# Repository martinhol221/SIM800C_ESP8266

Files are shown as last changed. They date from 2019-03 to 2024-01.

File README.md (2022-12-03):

* [Скачать актуальную версию прошивки 7.3 ](https://github.com/martinhol221/SIM800C_ESP8266/tree/master/firmware) обязательно перезалить дашборд
После перепрошивки зайти в меню прошивки через Web-интерфейс и сделать сброс настроек.

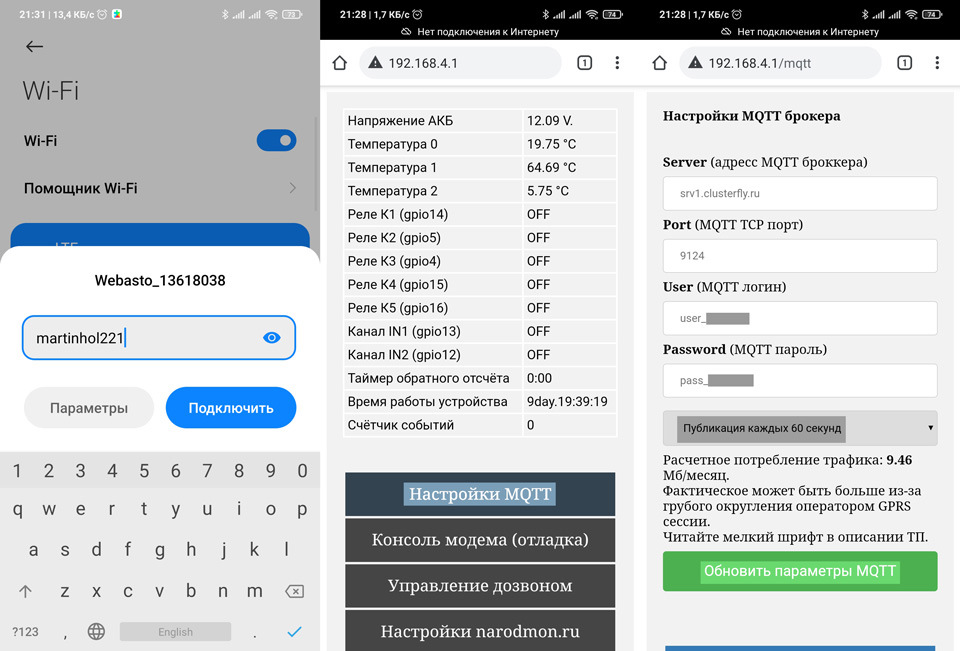
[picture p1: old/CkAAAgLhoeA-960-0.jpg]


Приложение CarMQTT Control

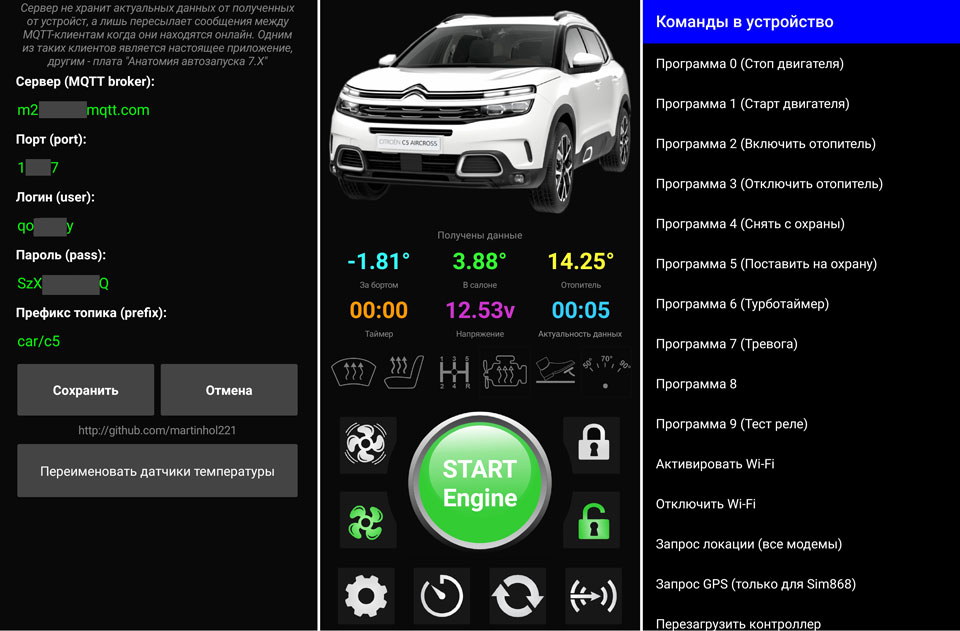
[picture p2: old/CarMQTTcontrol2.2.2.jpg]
* 

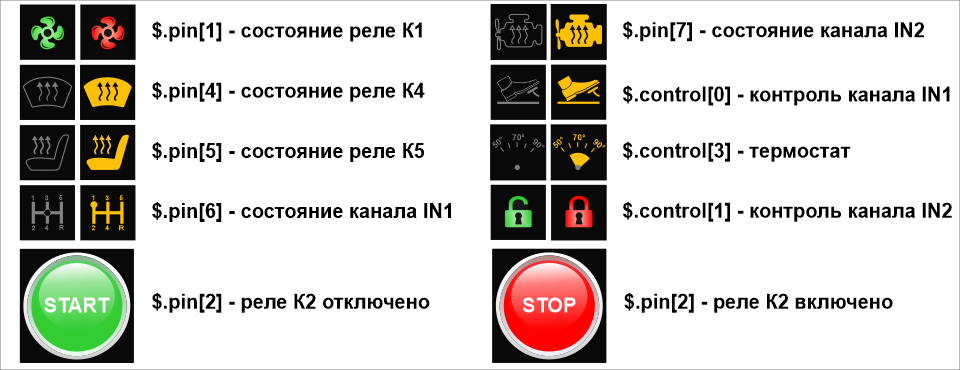
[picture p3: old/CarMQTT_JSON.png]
* 

## Коротко о протоколе MQTT в конкретной прошивке 

Приложение подписывается на топик `car/c5/pub` - и отправляет команды в топик устройства.
Устройство подписывается на топик `car/c5/sub` и реагирует на следующие сообщения в этом топике:

* `prog0`...`prog9` - исполняет одну из 10 програм храниящихся в настройках ESP8266
* `wifion`      - включает WI-FI точку доступа `Webasto_123456` с паролем `martinhol221`
* `wifioff`     - отключает WI-FI точку доступа
* `control1=1`  - активирует контроль за каналом IN1 (педаль тормоза, или другие функции)
* `control1=0`  - деактивирует контроль за каналом IN1
* `control2=1`  - активирует контроль за каналом IN2 (датчик удара, объема, или другие функции)
* `control2=0`  - деактивирует контроль за каналом IN2
* `termostat=1` - активирует контроль вилкой температур заданных в настройках (термостат, автопрогрев)
* `termostat=1` - деактивирует контроль температурой
* `termostat=0` - деактивирует контроль температурой
* `reboot` -  перезагрузка ESP8266
* `timer=15` - установка таймера обратного отсчета на 15 минут 
* `starter=1600` - установка максимального времени прокрутки стартера в 1.600 сек. 
* `ussd`  - публикует в топик `car/c5/pub/ussd` баланс	`Balans=5.00r MB=454` (только GSM кодировка)
* `debug` - публикует в топик `car/c5/pub/debug` JSON строку статистики соединения `{"debug":[1,0,0,0,5,5,1]}`
* `update`- публикует в топик `car/c5/pub`	JSON строку с данными текущего состояния 
`{"pin":[13.73,1,1,0,0,0,1,0],"temp":[14.81,14.50,14.13],"time":[45,3455,4],"control":[1,0,1,0]}`, извлечь необходимый параметр можно с помощью [JSON pach](https://github.com/json-path/JsonPath) доступного в большинстве MQTT приложений

* `$.pin[0]` - вернёт напряжение питания устройства (13.73)
* `$.pin[1]` - вернёт состояние реле `K1` (1) - включено
* `$.pin[2]` - вернёт состояние реле `K2` (1) - включено
* `$.pin[3]` - вернёт состояние реле `K3` (0) - отключено 
* `$.pin[4]` - вернёт состояние реле `K4` (0) - отключено
* `$.pin[5]` - вернёт состояние реле `K5` (0) - отключено 
* `$.pin[6]` - вернёт состояние входа `IN1` (0) - нет напряжения
* `$.pin[7]` - вернёт состояние входа `IN2` (1) - есть напряжение
* `$.temp[0]` - вернёт температуру датчика с индексом `0`  (14.81)
* `$.temp[1]` - вернёт температуру датчика с индексом `1`  (14.50)
* `$.temp[2]` - вернёт температуру датчика с индексом `2`  (14.13)
* `$.time[0]` - вернёт значение таймера обратного отсчета `45` минут 
* `$.time[1]` - вернёт время работы устройства `3455`
* `$.control[0]` -  контроль за каналом IN1 `1` активен (нейтральная передача)
* `$.control[1]` -  контроль за каналом IN2 `0` не активен (датчик удара)
* `$.control[3]` -  контроль за вилкой температур `0` не активен 

## Редактор програм

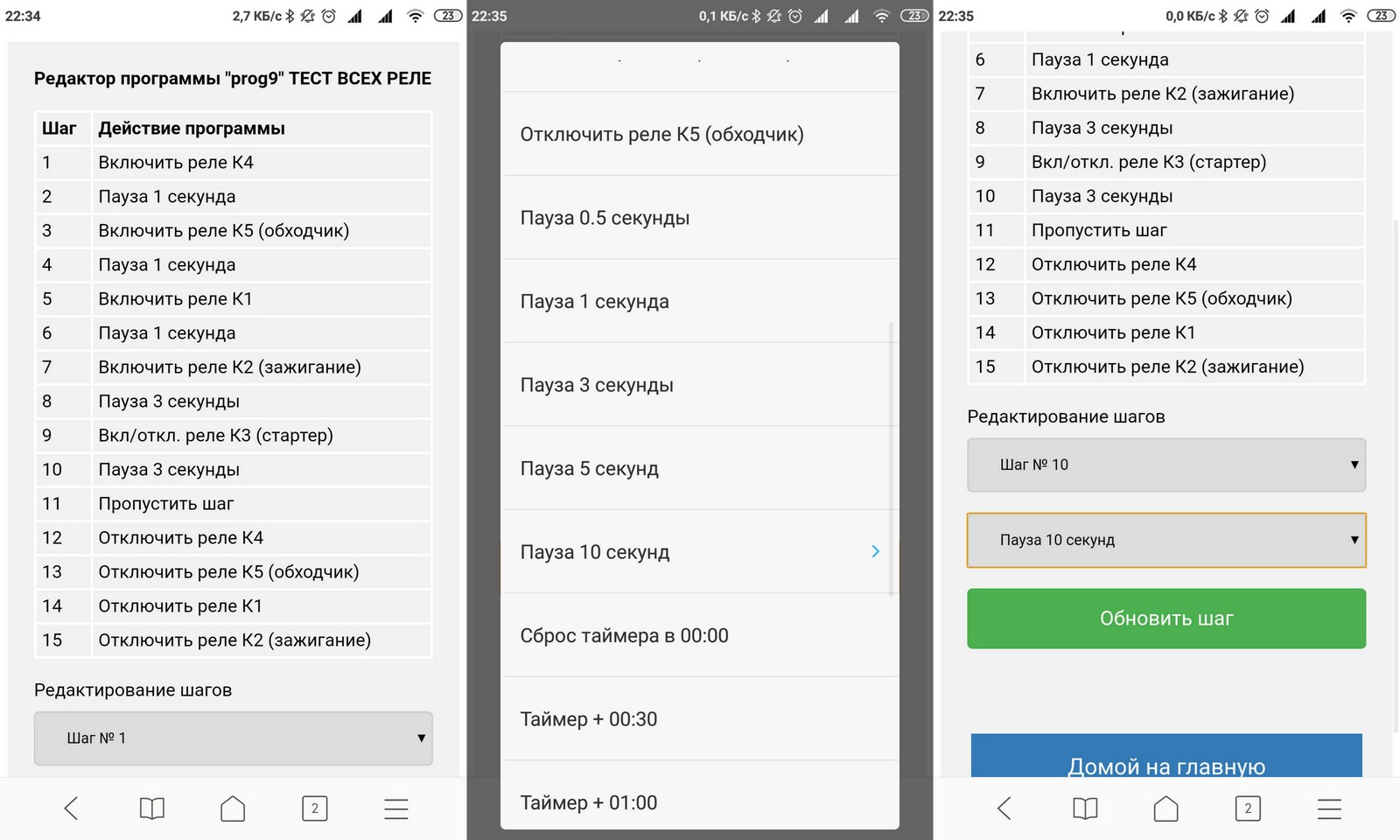
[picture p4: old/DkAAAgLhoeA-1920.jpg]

  
## Контроль включения стартера

В настройках интерфейса можно задать условие из трех пунктов для разрешение включения стартера в зависмости он напряжения АКБ  (при работающем двигателе оно будет выше 12,90V), и состояние каналов  `IN1` или `IN2`. обычно, они подключается на выход концевика педали тормоза (для АКПП), или на датчик включенной передачи (МКПП).

Длительность работы стартера задается в милисекундах (1 / 1000 сек.)

Поконтролю зарядки АКБ после запуска устройство понимает что двигатель запущен, контроль можно отключить.

## Контроль по аппаратному прерыванию каналов IN1 и IN2 и кнопке

* Cмена состояния каналов `IN1` или `IN2` с `0` на `12V` вызывает программы `prog0`... `prog9` заданные в настройках для этого канала
* Cмена состояния Кнопки с `3.3V` на `0` вызывает программы `prog0`... `prog9` или активации Wi-Fi

**********
## Управление по термостату

В настройках устройства задается:

* минимальная температура при падении ниже которой происходит вызов програм `prog0`... `prog9`
* максимальная температура при  превышении которой происходит вызов програм `prog0`... `prog9`
* индекс подключенного датчика с которого контролируется температура
* флаг активациии или деактивации режима

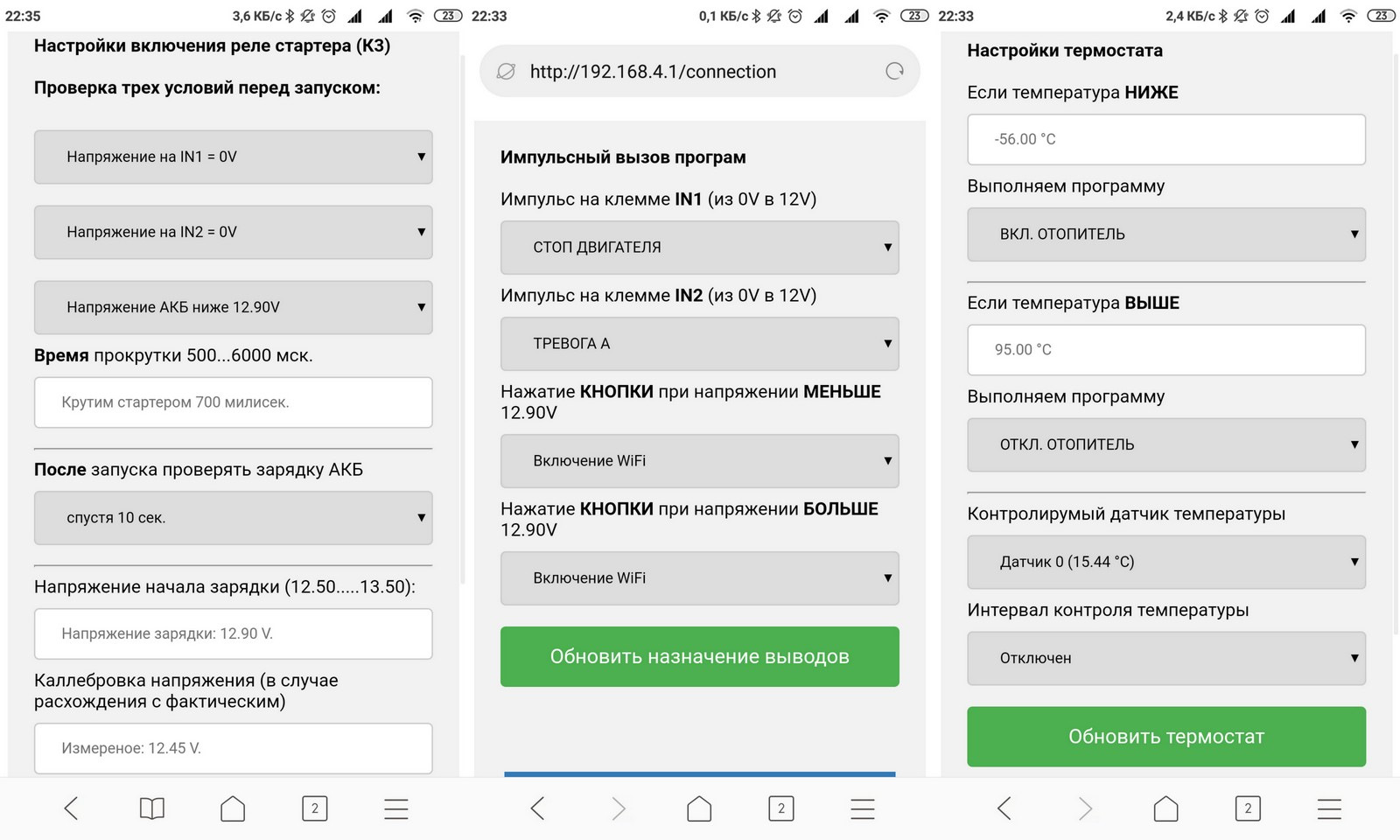
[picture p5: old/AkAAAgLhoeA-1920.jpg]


## Активация WI-FI точки доступа

Устройство генерирует точку доступа SSID `Webasto_123456` на 10 минут с паролем `martinhol221` , к которой можно подключиться с телефона для обновления прошивки или внесения изменений в настройки, страница настроек доступна по адресу `http://192.168.4.1`.
Активация WIFI возможна несколькими способами

* Запрос из приложения `wifion`
* Замыкание `SCL` на `GND` вызывает включение WiFi если это настроено в пункте контроля каналов.
* Снятие и подача питания на устройство

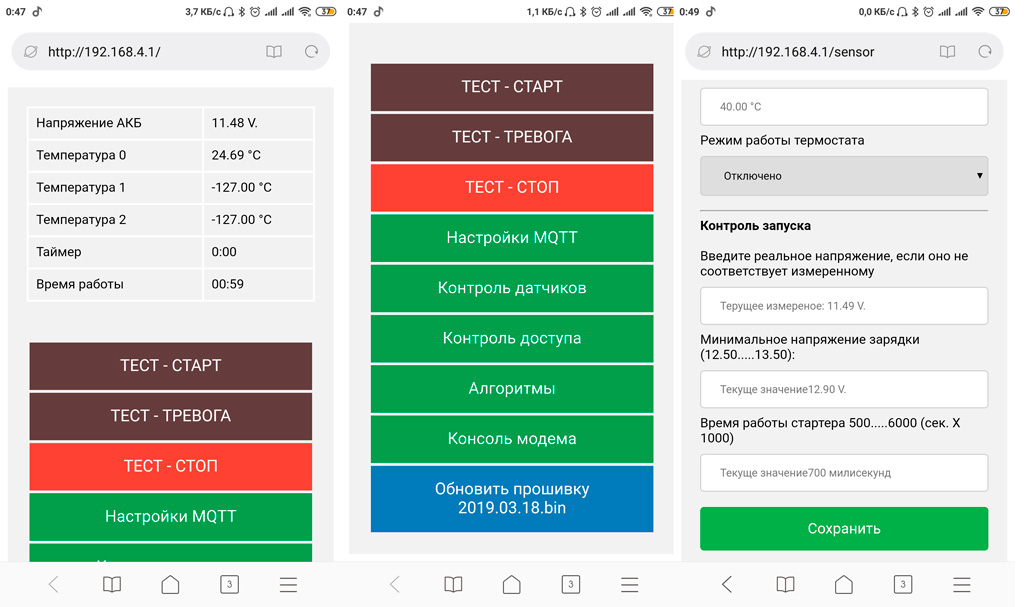
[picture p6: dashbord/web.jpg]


По прошествии 10 минут WiFi отключается и устройство уходит в энергосберегающий режим потребляя ток 17-22 мА.

## Управление по звонку с вводом DTMF команд

При звонке на устройство модем снимет вызов только с телефона хозяина, после "снятия трубки" будет ожидать ввода команд

* `#0*1234` - вызовет программу `prog0`
* `#1*1234` - вызовет программу `prog1`
* `#2*1234` - вызовет программу `prog2`
* `#3*1234` - вызовет программу `prog3`
* `#555`    - Отправит SMS через 10 сек. 
* `#777`    - Перезагрузит модем. 
* `#888`    - активирует вайфай. 
* `#999`    - Перезагрузит ESP. 

где `1234`     - пинкод для управления   

****
## управление GET-запросом
http://192.168.4.1/sensor?name1=TEMP4&val1=-12.24   // Передача на narodmon.ru значения датчика -12.24 с именем TEMP4  

http://192.168.4.1/set?PROG=0                       // Выполнить программу 0 - (СТОП)

http://192.168.4.1/set?PROG=6                       // Выполнить программу 6 

http://192.168.4.1/set?AT_CMD=ATD%2B37512345678%3B // Звоним на нужный номер +37512345678  

http://192.168.4.1/set?AT_CMD=ATH0                  // Завершаем вызов

http://192.168.4.1/sms?sms_phone=%2B3751234567&sms_text=Trevoga.Datchik1 // отправка sms 

## Выбор MQTT приложения в телефон для управления по GPRS

Для Android
* [MQTT Strt Engine (специально написанное)](https://play.google.com/store/apps/details?id=appinventor.ai_martinhol2221.CarMqttControl)
* [MQTT Dash Google Play](https://play.google.com/store/apps/details?id=net.routix.mqttdash&hl=ru) рекомендую
* [IoT MQTT Panel](https://play.google.com/store/apps/details?id=snr.lab.iotmqttpanel.prod)
* [IoT MQTT Dashboard](https://play.google.com/store/apps/details?id=com.thn.iotmqttdashboard)
* [Linear MQTT Dashboard](https://play.google.com/store/apps/details?id=com.ravendmaster.linearmqttdashboard)

Для IOS: 
[IoT OnOff](https://itunes.apple.com/be/app/iot-onoff/id1267226555?mt=8) не на всех версиях ОС, может не коннекстится с брокером

## Выбор MQTT брокера (далее сервера)

**********************************

MQTT broker

https://www.cloudmqtt.com

https://clusterfly.ru

https://wqtt.ru

http://mqtt.by

### Потребление трафика:

Один пакет GPRS данных состоит в среднем из 100 - 110 байт, отправляется устройством каждую минуту, 100 байт х 60 минут х 24 часа х 31 день = около 4.5 MB/мес, однако на практике оператор трафик считают больший, у меня набегает 9.5 Мб в месяц.
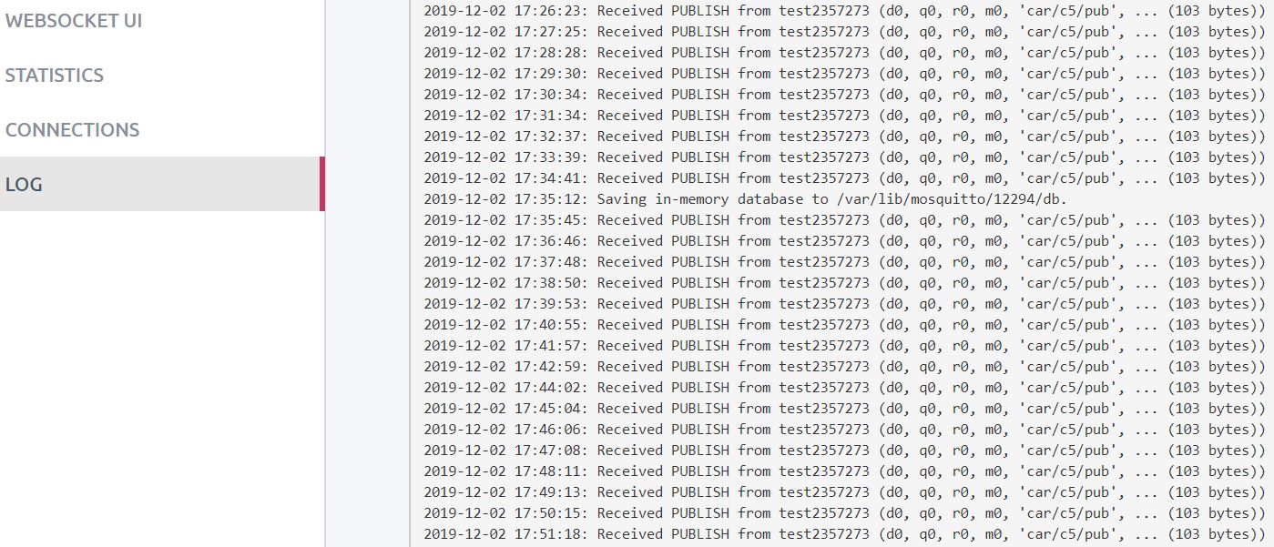
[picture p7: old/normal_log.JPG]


Стоит отметить что сотовые операторы по разному округляют трафик в конце сессии, в результате чего, списывать с баланса могут в разы больше фактически затраченного.



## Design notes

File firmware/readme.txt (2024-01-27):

SSID: Webasto_XXXXXXX (10 min.)
PASS: martinhol221

ESP-12E OR ESP-12F
ADDR: 0x00000

ESP-8266    --> SIM800C (SIM800L) 
TXD (GPIO1) --> RXD
RXD (GPIO3) --> TXD

1-Wire (DS18B20, DS2413) - GPIO0 
Button on PCB- GPIO2
IN1- GPIO13  
IN2- GPIO12 

распиновка реле:
K1-  GPIO14  
K2-  GPIO5  
K3-  GPIO4  
K4-  GPIO15  
K5-  GPIO16  

07.10.2019 - добавил опцию выгрузки / загрузки настроек через JSON строку
12.10.2019 - имена програм можно редактировать, добавил кнопку "назад в редактор", из приложенимя можно "привязывать" 
первый и второй какналы к программам prog0 ... prog9. после перепрошивки делаем сброс настроек до заводских настроек
19.10.2019 - имя и пароль wifi сети сохраняется после перезагрузки, побавил возможность внутри выполняемой программы 
включать и отключать выполнение програм по инмпульсам на каналах IN1 (prog0) и IN2 (prog7). 
29.10.2019 - контроль температуры термостатом происходит один раз в минуту, 5 ошибок `+CME ERROR: 3` подряд перезагружает
модем востанавливая связь, программы prog0....prog7 исполняются только ОДИН РАЗ подряд, вне зависимости от источника 
их вызова, если предыдущая прошивка свежее 19.10.2019 то сбрасывать настройки не нужно
31.10.2019 - пофиксил баг с пропаданием связи после 'длинных' програм запуска, 5 ошибок `CLOSED` подряд перезагрузит модем.
02.11.2019 - При звонке на симку DTMF ввод 888 активирует вайфай, ввод 777 перезагружает модем.
06.11.2019 - увеличелось время отклика, повысилась стабильность соединения, 
появилась статистика {"debug":[CONNECT OK,CONNECT_FAIL,+CME ERROR,CLOSED,пакетов отправлено, подтверждено, перезагрузок
модема]}
08.11.2019 - пофиксил баг с некоррректным определением DTMF команд перезагрузка модема `777`, вкл. WIFI `888`, перезагрузка 
всего `999` 
16.11.2019+ - отключил функцию LWT нужен тест на длительность, костыли для стабильности 5 `CLODED` (5 минут) - перезагрузка
модема, 5 - перезагрузок модема (30 минут) - перезагрузка ESP (сброс времени работы) 
30.11.2019 - изменён режим комнотроля каналов IN1 и IN2, и режим активации термостата, сейчас ставить пины на контроль можно из 
дашборда (который так же нужно обновить)
16.12.2019 - измененено условие перезагрузки модема: 7 ошибок `CLODED` ТОЛЬКО ПРИ УСЛОВИИ что модем ЗАРЕГИСТРИРОВАН в сети,
ошибка будет игнорироваться, если модем вне сети покрытия. Появился режим 'Стартер по тахометрту' - отключение стартера в 
процессе запуска, при условии, что импульсы с датчика распредвала (IN2 до 12V) будет меньше XXX милискунд, которые 
устанавливаются на странице настроек стартера, у меня нет возможность тестировать.
11.01.2020 - Добавлена поддержка виртуальных реле К6 - К13 через расширитель портов на DS2413 подключаемого к шине датчиков.
14.01.2020 - Исправил баг с отключением WIFI после перезагрузки, когда в настройках стояло `Не выключать`.
10.02.2020 - Исправил баг из-за которого контроллер " забывал " выключать включенные реле при перезагрузке. Добавил выгрузку данных на народмон, скрытая страница 192.168.4.1/narodmon
18.02.2020 - Выделена отдельная кнопка настроек народмон, востановление забытого пароля wifi: подать питание и в течении 0,5 сек зажать
кнопку на 2 сек. и отпустить, код загрузится с настройами по умолчанию. Раньше для входа в безопасный режим нужно было подавать 5-6 вольт при подаче питания, что было не удобно.
08.03.2020 - по MQTT уходит время наработки в часах, таймер обратного отсчёта в секндах, работает стабильно с mqtt.4api.ru
21.03.2020 - GET запрос http://192.168.4.1/sensor?name1=TEMP4&val1=-12.24&name2=TEMP5&val2=14.68 с показаниями датчиков будет ретранслирован в народмон
21.07.2020 - добавлен сканер устрйств на однопроводной шине данных, счётчик событий, опция в программе разрешающая ее повтор множество раз подряд.
19.09.2020 - добавлен вывод данных о состоянии всех выходов и статистика по подключению модема для приложения CarMQTTControl (вызов через " Управление - Диагностика")
17.01.2021 - сделана автоматическая генерация преффиксов топиков при обновлении настроек MQTT, данные по диагностики сейчас притетают вcar/c5/pub/diagnostics
ответ {"status":[0,0,0,0,675,675,0,3,97,692]}, для этого изменена подписа в приложении начиная с CarMqttControl_2.2.6 и выше
16.10.2021 - добавил опцию задержки (2 минуты) выключения реле К1, будет полезно при использовании циркуляционного насоса вебасто.
19.10.2021 - добавил опцию задержки (3 минуты) включения реле К4, будет полезно для активации климат-контроля
23.10.2023 - крупное обновление;
- Изменена разметка страницы, шрифты, перенесены разделы по другим категориям;
- Полностью переписан интерфейс редактора сценариев, увеличено количество шагов до 20-ти сразу для всех сценариев, исчез глюк с недогрузкой страницы. Стало возможно редактирование всех 20 шагов не покидая страницу и сохраняя их залпом все сразу;
- Изменена разметка страницы консоли модема, сейчас текст не вылазит за пределы страницы;
- При установке пин-кода 0000 в настройках вызова, при дозвоне происходит сброс вызова и запуск сценария 1;
- Содержимое страницы настроек каналов переехало на страницу настроек сценариев;
- На страницу настройки стартера добавил поле минимального напряжения для включения стартера, будет полезно при автопрогреве, если не произошёл запуск несколько раз подряд и аккум высел ниже этого порога то автопрогрев (термостат) отключается что бы не убивать далее АКБ.
- При проверке каналов IN1 и IN2 перед запуском ранее к двум логическим состояниям добавил "любое состояние", временно убрал поле для тахометра, позже верну.
- Скрыл кнопку перехода на страницу настройки народмона из-за бага с ошибкой +CME Error 3, сама настройки по пержнему доступна по адресу 192.168.4.1/narodmon;
- В новой прошивке сдвинулись реле, теперь реле K6 и К7 пока не задействованы, а все реле реализованные через расширитель портов сейчас отображентся как порт 1А, порт 1B и т.д. и работают в импульсном режиме (вкл. пауза 1 сек., выкл.)
- Полностью пересмотрена структура JSON файла для хранения настроек, от этого после перехода на новую прошивку активация не подтягивается и настройки вытавляются по умолчанию, ключ нужно прописывать заново;
Можно обновиться до новой прошивки, не активируя ее старым ключом, поизучать и снова прошиться старой прошивкой от октября 21 октября 2021 и настройки восстановятся.

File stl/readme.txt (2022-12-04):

4x18650-TK102B -  переходник для крепления 4х аккумуляторов формата 18650 платы GPS треккера TK-102B
PSA_ring_41.5 - кольцо на антенну иммобилайзера замка зажигания Пежо, Ситроен 
Renault_ring_59.5 - кольцо на антенну иммобилайзера замка зажигания Рено, Веста 
PCF7936 - каркас катушки чипа транспондера.
Mazda-6 - каркас катушки с квадратным отверстием 14х14 мм

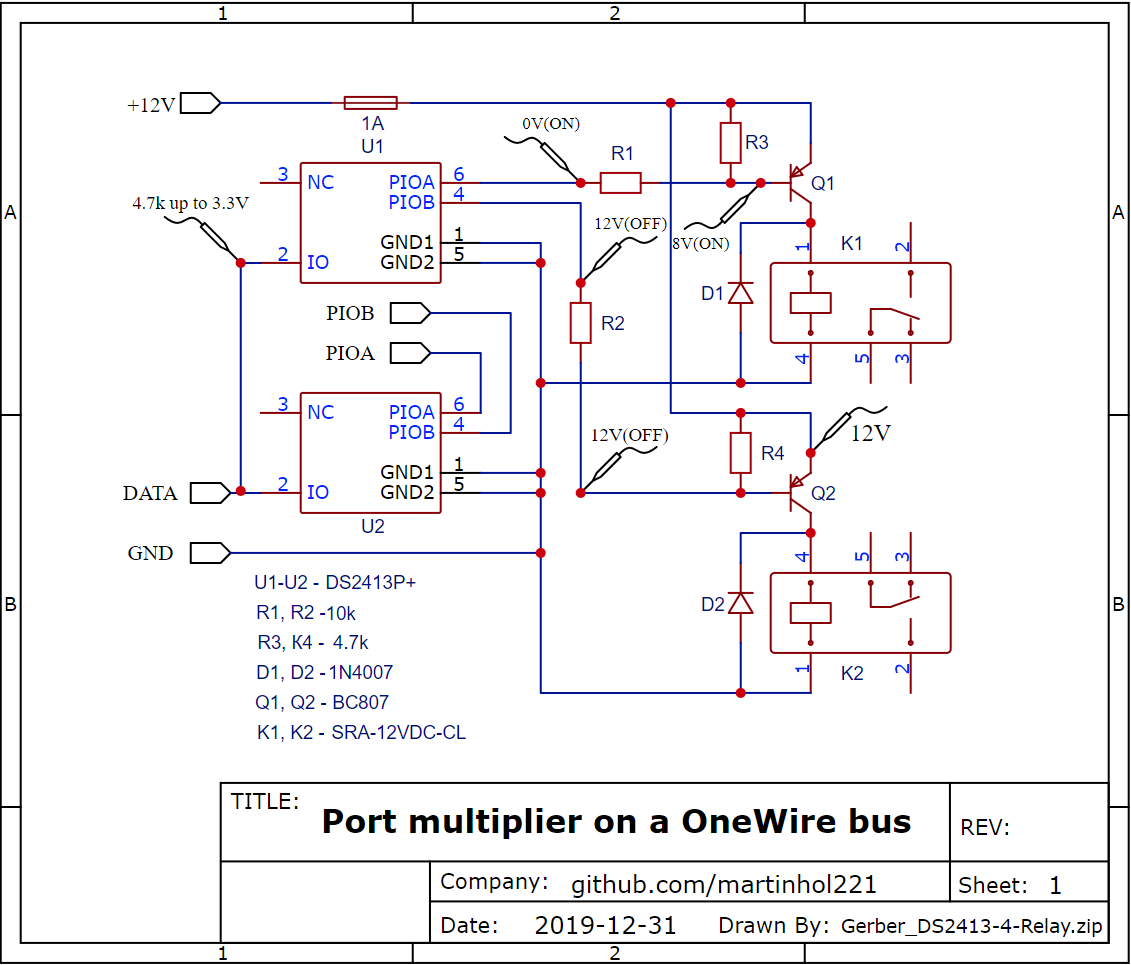
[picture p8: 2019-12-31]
PCB/DS2413-2-Relay.png

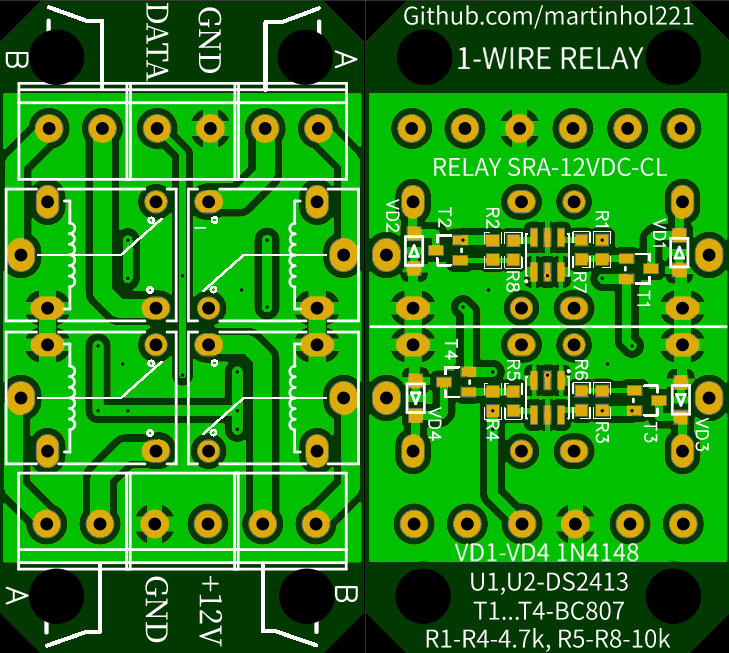
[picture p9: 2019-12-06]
PCB/Gerber_DS2413-4-Relay.jpg

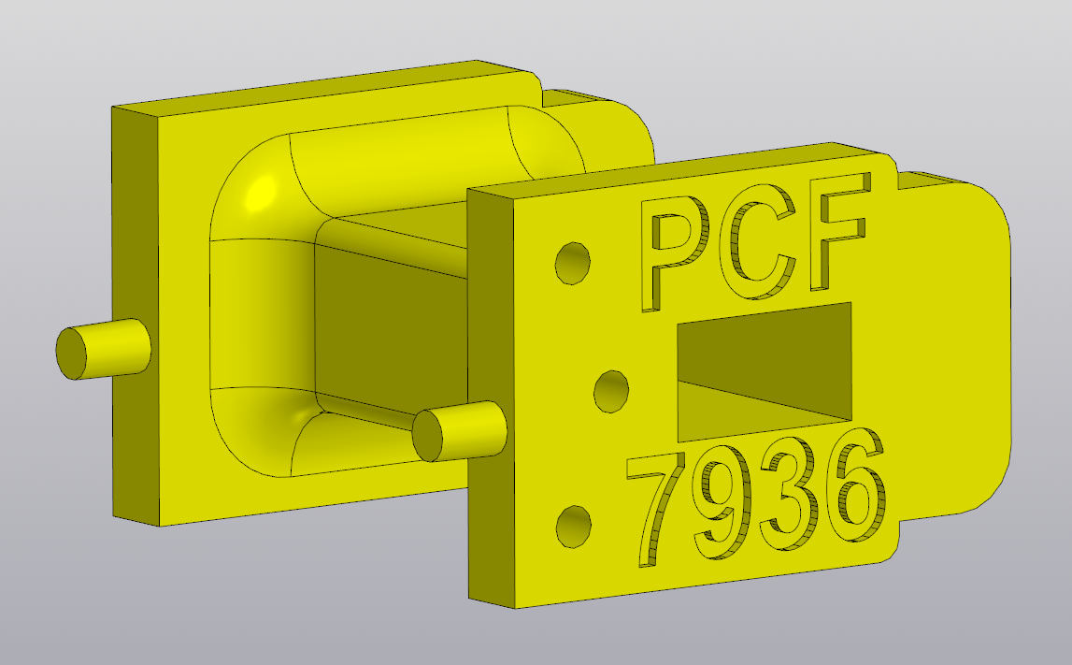
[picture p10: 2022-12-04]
stl/PCF7936.png

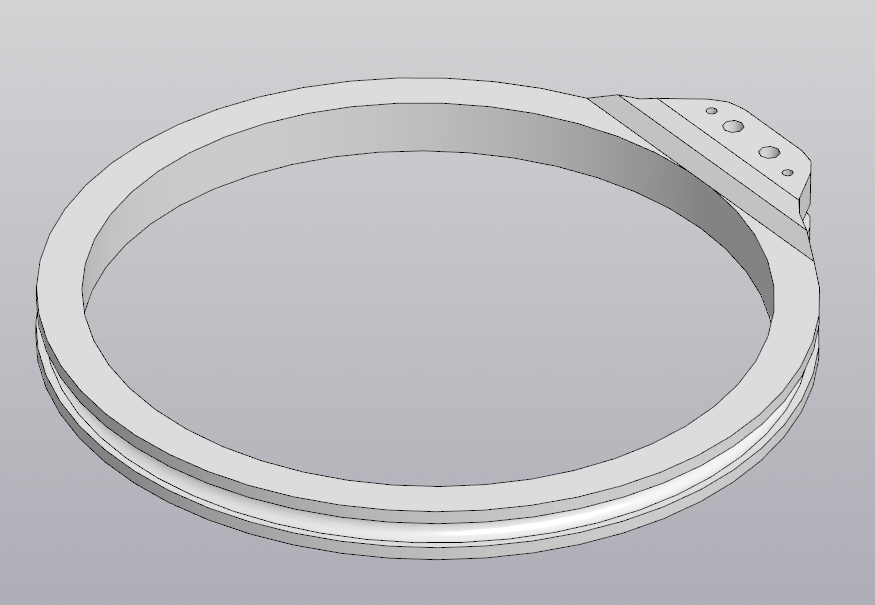
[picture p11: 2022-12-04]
stl/Renault_ring_59.5.png

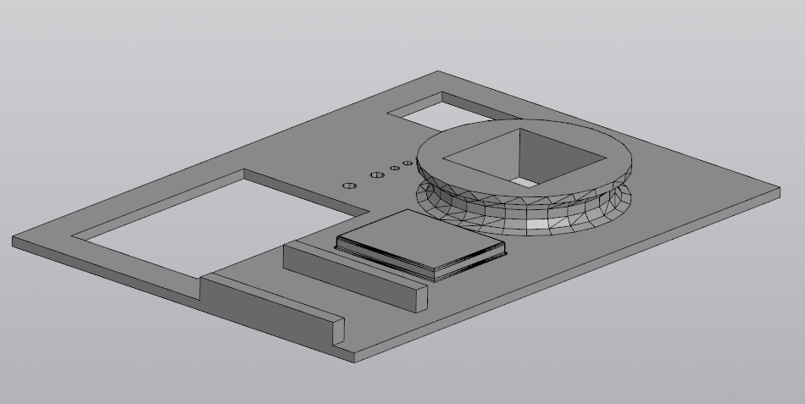
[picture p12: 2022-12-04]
stl/Mazda-6.png

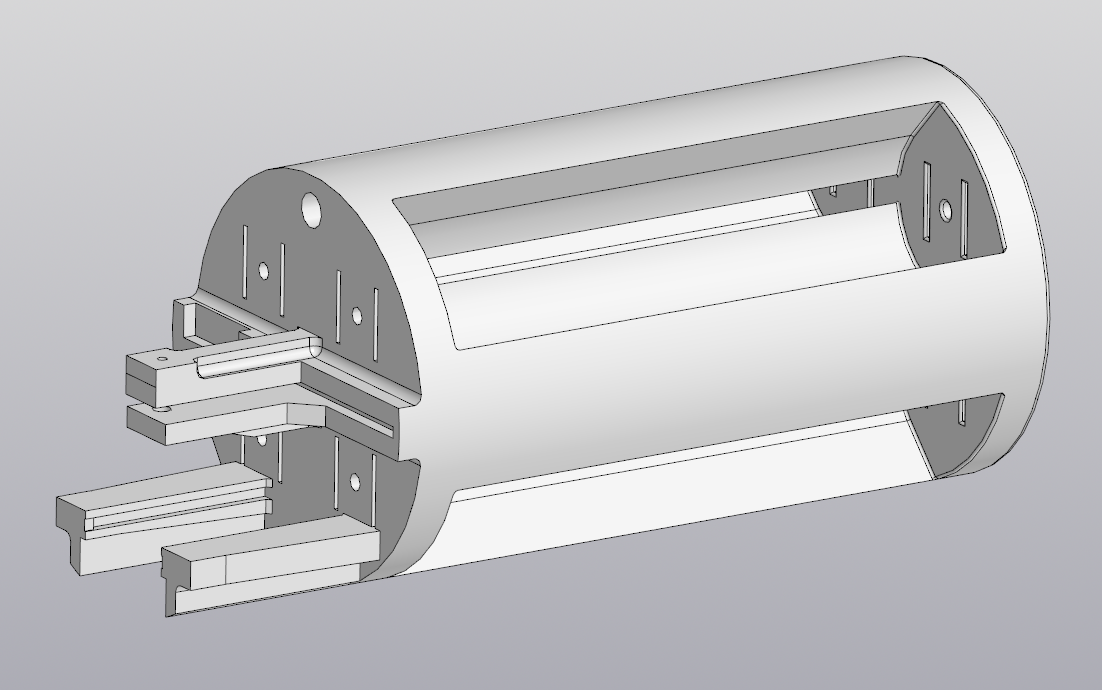
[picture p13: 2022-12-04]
stl/4x18650-TK102B.png

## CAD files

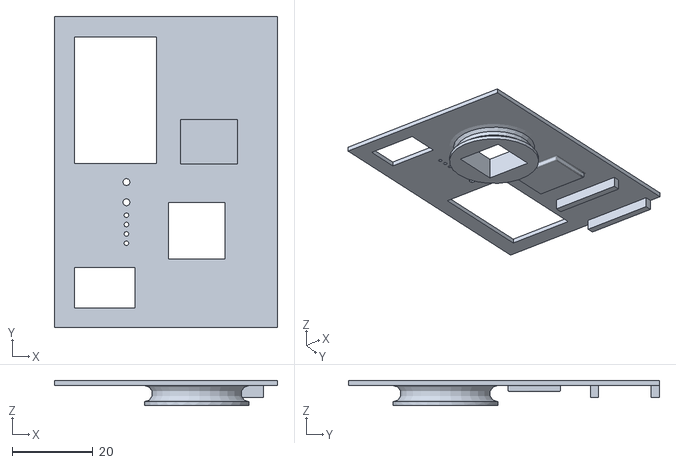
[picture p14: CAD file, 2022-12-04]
stl/Mazda-6.stl
55.3 x 77.0 x 6.30

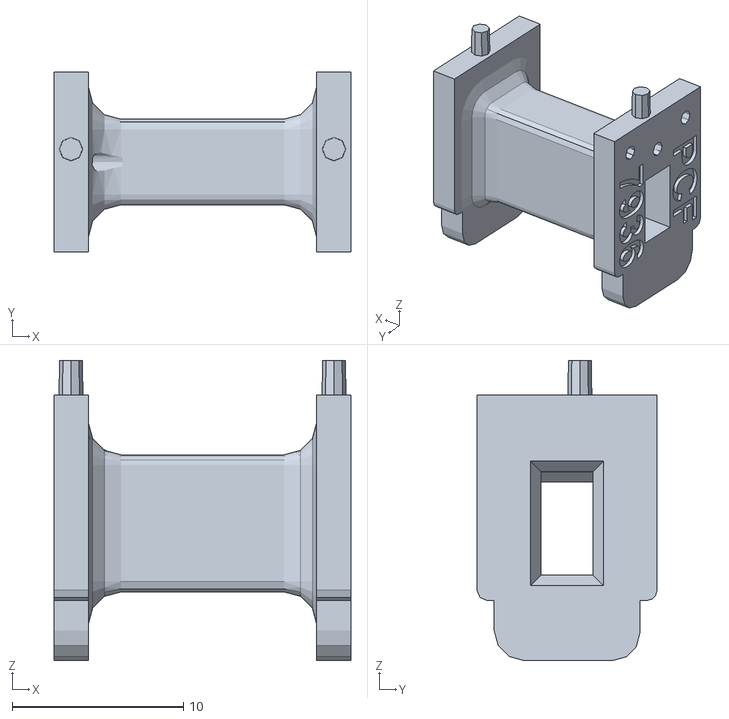
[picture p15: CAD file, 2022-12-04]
stl/PCF7936.stl
17.3 x 10.5 x 17.5

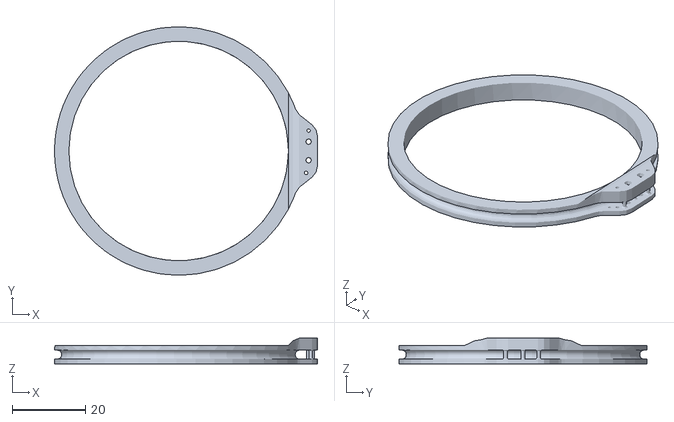
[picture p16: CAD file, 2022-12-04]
stl/Renault_ring_59.5.stl
72.0 x 68.0 x 7.00

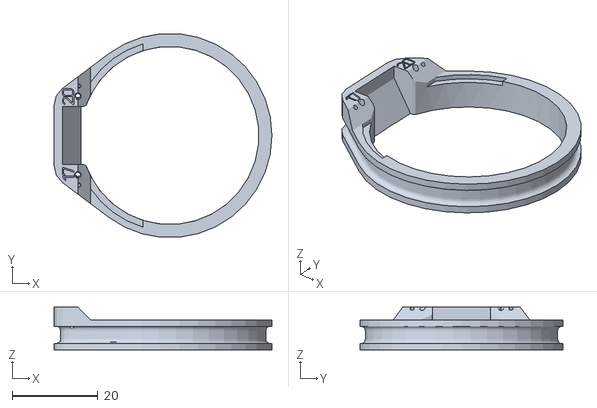
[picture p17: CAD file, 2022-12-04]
stl/PSA_ring_41.5.stl
50.9 x 47.5 x 10.0

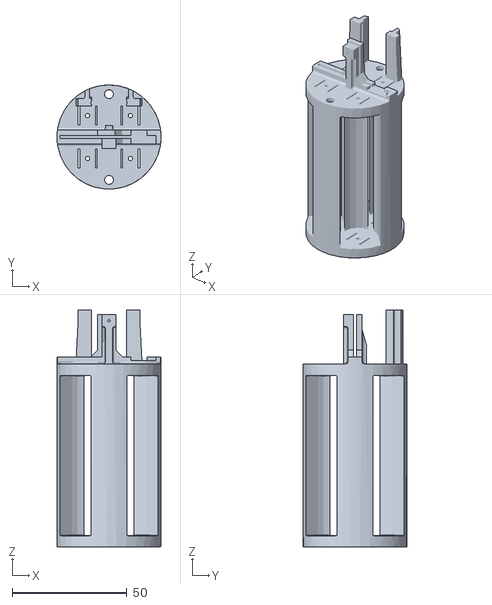
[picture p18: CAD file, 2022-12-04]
stl/4х18650-TK102B.stl
45.5 x 45.5 x 103.5

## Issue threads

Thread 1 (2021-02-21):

Шаги программы

ekkeer, 2021-02-21:
**_Больше шагов, богу шагов._**
В некоторых случаях требуется большее количество шагов в той или иной программе, планируется ли увеличение количества шагов, и чем обусловлено их ограничение?
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

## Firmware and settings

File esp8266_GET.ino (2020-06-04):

#include <ESP8266WiFi.h>
#include <WiFiClient.h>
WiFiClient client;
ADC_MODE(ADC_VCC);
#include <DallasTemperature.h> 
#define ONE_WIRE_BUS 0             // GPIO2 (ESP8266) > DATA (DS18B20)
#define PIN_POWER_DS 5             // GPIO5 (ESP8266) > VCC  (DS18B20)
OneWire oneWire(ONE_WIRE_BUS);
DallasTemperature sensors(&oneWire);
int count, inDS = 5;               // Количество датчиков на шине
int sleep = 300;                   // Время сна
const char *ssid = "Gateway";      // SSID шлюза (платы анатомия автозапуска 7.3)
const char *pass = "martinhol221"; // Пароль шлюза 
String host = "192.168.4.1";

void setup() {
bool pin4 = digitalRead(4);
pinMode(PIN_POWER_DS, OUTPUT); digitalWrite(PIN_POWER_DS, HIGH); 
Serial.begin(115200), Serial.println(), Serial.println();
Serial.print("https://github.com/martinhol221/ESP-8266 | esp"), Serial.println(ESP.getChipId());
Serial.println("Conecting to: SSID:"+String(ssid)+" | PASS:"+String(pass));
WiFi.mode(WIFI_STA); WiFi.begin(ssid, pass);



while (WiFi.status() != WL_CONNECTED) {count++, delay(500),  Serial.print("#");
                                       if (count > 40) Serial.println("DeepSleep 10 min"), delay(1000), ESP.deepSleep(10*60*1000000);}
Serial.print(" - > IP:"), Serial.println(WiFi.localIP());

//if (pin4 != 0) get_reqest("GET /sensor?name1=RSSI&val1="+String(WiFi.RSSI())+"&name2=ADC&val2="+String(ESP.getVcc()));
if (pin4 != 0) ds18b20_get();
//SMS_get("375291234567", "Privet.%20Srabotal%20datchik!"); // отправка SMS на номер без "+37520XXXXXX" , "сообщение на латинице c заменой пробела на %20" )
//Call_get("375291234567");                                 // звонок на номер
if (pin4 == 0) program_get(6);                              // запуск программы №

Serial.println("Uptime: "+String(millis())+" millisec.");
Serial.println("DeepSleep "+String(sleep)+" sec."); delay(100), ESP.deepSleep(sleep*1000000);
}

// http://192.168.4.1/sensor?name1=TEMP4&val1=-12.24
void ds18b20_get() {
String buf = String(ESP.getChipId())+"&rssi="+String(WiFi.RSSI())+"&adc="+String(ESP.getVcc());
sensors.begin(); delay(1000); 
sensors.requestTemperatures();
for (int x=0; x < inDS; x++) buf +="&name"+String(x+1)+"=TEMP"+String(x+4)+"&val"+String(x+1)+"="+ String(sensors.getTempCByIndex(x));
get_reqest("GET /sensor?id="+buf);}

void program_get(int program)              {get_reqest("GET /set?PROG="+String(program));}  
void Call_get(String phone)                {get_reqest("GET /set?AT_CMD=ATD%2B"+phone+"%3B");}
void SMS_get(String phone, String smsText) {get_reqest("GET /sms?sms_phone=%2B"+phone+"&sms_text="+smsText);}

void get_reqest(String url)     { 
    if (client.connect(host, 80)) {
                                  String buf = url+" HTTP/1.1\r\nHost: "+host+"\r\nConnection: close\r\n\r\n";
                                  client.println(buf); Serial.println(buf);
                                  } else Serial.println("Хост: "+host+" недоступен"); 
                                }


void loop() {
            }

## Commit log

2018-12-11 Добавил DTMF декодер
2018-12-24 Отпарвка СМС из шаблона команд, тест
2018-12-26 Плностью активно СМС уведомление после старта
2019-01-15 не допил
2019-01-26 только для прошивки версии 7.2
2019-01-27 ТЕСТ
2019-01-27 Версия 7.2, для тех кто разобрался с 7.0
    ТЕСТ
2019-01-30 обновил информатор заруска при звонке
    cейчас при звонке и вводе 1*пинкод, произойдет запуск на и через 6 сек проверка напряжения, в случае не запуска 5 гудков, в случае запуска "повесит трубку"
2019-01-31 только для устройств на плате 7.0
    другая распиновка реле
2019-02-01 Полная приборная панель
2019-02-01 Легкая версия дашборда
2019-02-03 добавил SMS оповещения
2019-02-11 только для плат 7.0 с вырезом!
2019-02-12 только для плат 7.0 (стартер на среднем реле)
2019-02-17 Принципиальная схема версии 7.2
2019-02-23 обновлены шаблоны блютуз команд
2019-02-24 только для плат 7.0 (с фрейзеровкой в углу)
2019-03-17 Add files via upload
    ДЛЯ ВСЕХ ПЛАТ КРОМЕ 7.0
2019-03-17 Add files via upload
    Только для плат 7.0 (с вырезом в углу)
2019-03-17 Для всех плат кроме 7.0
2019-03-18 Только для плат 7.0
    Обновить дашборд
2019-03-18 Для всех плат кроме 7.0
    Перезалить дашборд
2019-03-23 добавил CaptivePortal
2019-09-26 Дашборд для прошивки после сентября 2019
    Дашборд приложения MQTT Dasch для прошивки после сентября 2019
2019-09-29 Последняя прошивка за сентянябрь
2019-10-01 Дашборд к прошивке за март 2019
2019-10-01 Файл конфигурации приложения MQTT Dasch
2019-10-01 Актуальная прошивка для плат версии 7.1 и выше
2019-10-07 исправлен баг по стартеру
2019-10-07 Только для платы 7.0
2019-10-07 устаревшая версия
2019-10-07 только для 7.0
2019-10-19 Стабильная версия
2019-10-19 Только для плат 7.0
    Другое подключение реле К2-К5
2019-10-19 ТЕСТ
    ТЕСТ, защита от выполнения программы два раза подряд
2019-10-21 Для прошивки за октябрь 2019
2019-10-29 Only Relay K2
2019-10-31 Только для плат 7.0
2019-10-31 Для всех плат выше 7.0
2019-11-06 улучшена стабильность передачи данных
2019-11-16 только для версий 7.0
2019-11-17 5 перезагрузок модема - перазагрузка ESP
2019-11-23 подписка только на car/c5/sub
2019-12-01 Стабильная прошивка под новый дашборд
2019-12-02 нормальный лог
2019-12-06 Расширитель портов на DS2413
2019-12-27 только для версий платы 7.0
2019-12-30 Принципиальная схема расширителя пота на DS2413
2020-01-11 Добавлен расширитель портов на DS2413
2020-02-10 fix all relay off
2020-02-20 только для версии платы 7.0
2020-03-23 GET request 192.168.4.1
    http://192.168.4.1/sensor?name1=TEMP4&val1=-12.24&name2=TEMP5&val2=14.68
2020-04-24 MQTT клиент для анатомии автозапуска 7.X
2020-04-26 Andoid приложение для анатомии автозапуска 7.X
    MQTT клиент
2020-04-27 Andoid приложение для анатомии автозапуска 7.X
2020-05-04 настройки для mqtt.flyhub.org
2020-05-26 востановительная прошивка
2020-07-23 Сканер 1-Wire шины, счётчик событий
2020-09-11 добавлен запрос на диагностику,
    добавлен запрос на диагностику, выведен счётчик событий
2020-11-01 Обратный отсчёт для кнопки START/STOP
2021-01-17 для прошивок 2021 года
2021-01-19 для CarMqttControl_2.2.6 и выше
2021-01-26 переименовывайте сценарии
2021-10-16 K1 (gpio14) timer off
2022-12-04 Исходники 3D. моделей
2023-09-16 Добавлена возможность менять картинку. тест
